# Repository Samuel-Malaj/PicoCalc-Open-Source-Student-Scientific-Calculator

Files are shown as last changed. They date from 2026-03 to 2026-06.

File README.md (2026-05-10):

# PicoCalc-Open-Source-Student-Scientific-Calculator
Open source scientific calculator built on Raspberry Pi Pico W — custom PCB, WiFi messaging, IR projector control and games.

# PicoCalc — Open Source Student Scientific Calculator

A fully custom scientific calculator built on the Raspberry Pi Pico W, designed specifically for students. Features wireless peer-to-peer messaging, IR classroom projector control, a custom PCB, and built-in games — all running on MicroPython.

---

## Overview

PicoCalc is an end-to-end hardware and software project encompassing PCB design, embedded systems programming, wireless networking, and circuit design. Every component — from the button matrix to the IR driver circuit — was designed, calculated, and implemented from scratch.

This project was built entirely by a Year 10/11 student as an independent engineering project.

---

## Features

### Scientific Calculator
- Full arithmetic operations with correct operator precedence
- Scientific functions: sin, cos, tan, log, ln, sqrt, powers, factorials
- Degree and radian mode switching
- Expression history and ANS recall
- Error handling for invalid inputs and edge cases
- Custom expression parser built from scratch in MicroPython

### Peer-to-Peer Messaging
- Send and receive text messages between two PicoCalc devices over WiFi
- UDP broadcast protocol for low-latency local communication
- Designed for classroom use — share working, answers, or notes with a friend

### IR Projector Control
- 940nm IR LED with BC547 transistor driver circuit
- Compatible with Hitachi, Maxell, Epson and Samsung projectors and displays
- Up to 10 metre range achieved through transistor amplification
- Allows students to control classroom projectors from their desk
- NEC and SIRC IR protocol support

### Games
- Built-in simple games for use during breaks
- Runs entirely on the calculator hardware — no additional software needed

---

## Hardware

### Custom PCB
- Designed from scratch in KiCad
- Manufactured by PCBWay
- 2-layer PCB with row traces on F.Cu and column traces on B.Cu
- Dimensions: 75.5mm × 146mm

### Components
| Component | Description |
|---|---|
| Raspberry Pi Pico W | Main microcontroller with WiFi and Bluetooth |
| 38× 6mm Tactile Switches | Button matrix (THT, through hole) |
| TSAL6200 | 940nm IR LED, 3mm horizontal |
| BC547 | NPN transistor for IR LED driver |
| 22Ω Resistor | IR LED current limiting |
| 1kΩ Resistor | Transistor base protection |
| 2.42" SSD1309 OLED | 128×64 I2C display |
| 2× AA Battery Holder | MPD BC2AAPC, powers via VSYS |

### Button Matrix
- 38 buttons arranged in a row/column matrix
- GP0–GP7: row outputs
- GP8–GP15: column inputs with internal pull-up resistors
- Only 16 GPIO pins required for 38 buttons
- Scanning rate fast enough to never miss a keypress

### IR LED Circuit
- VSYS (3V from 2× AA) powers the LED circuit
- 22Ω current limiting resistor → 82mA through LED
- BC547 transistor switches the high current safely
- GPIO only supplies <2.6mA to the base — well within Pico's 16mA limit

### Power
- 2× AA batteries connected to VSYS pin
- Auto power-off via MicroPython lightsleep after inactivity
- Lightsleep current draw: ~1-2mA — significantly extends battery life

---

## Software

### MicroPython
- Written entirely in MicroPython
- Modular codebase — calculator, display, networking, IR all separate modules
- Custom expression parser for evaluating scientific expressions
- Uses built-in `math` library for scientific functions

### WiFi Communication
- Both devices connect to the same network
- UDP sockets for low-latency message transmission
- Graceful handling of connection drops and reconnection

---

## PCB Design

Designed in KiCad. Key design decisions:

- **2-layer routing**: Row traces on F.Cu, column traces on B.Cu — allows the button matrix grid to work without short circuits
- **Through hole components**: All buttons and connectors are THT for mechanical strength under repeated use
- **RF keepout zone**: Respected around the Pico W antenna to preserve WiFi/BLE signal strength
- **Removable Pico**: THT header holes allow the Pico W to be plugged in and removed — not permanently soldered
- **Battery on reverse**: Battery holder mounted on B.Cu to keep the front face clean

---

## Schematic & Design Files

- KiCad schematic and PCB layout files included in `/hardware`
- Gerber files included in `/hardware/gerbers`
- BOM included in `/hardware/BOM.csv`

---

## What I Learned

- PCB design and manufacturing process (KiCad → Gerber → PCBWay)
- Ohm's law applied to real circuit design (resistor calculations for IR LED and transistor)
- Button matrix design — why a matrix uses N+M pins instead of N×M
- Two-layer PCB routing and via usage
- MicroPython embedded programming on real hardware
- WiFi networking with UDP sockets on microcontrollers
- IR remote control protocols (NEC, SIRC)
- Debugging real hardware and firmware issues

---

## Project Status

- [x] PCB designed and ordered
- [x] Schematic complete
- [ ] IR LED circuit designed and verified
- [x] MicroPython calculator engine
- [ ] Display driver integration
- [x] WiFi messaging
- [ ] IR control implementation
- [ ] Games

---

## License

MIT License — free to use, modify and build upon.

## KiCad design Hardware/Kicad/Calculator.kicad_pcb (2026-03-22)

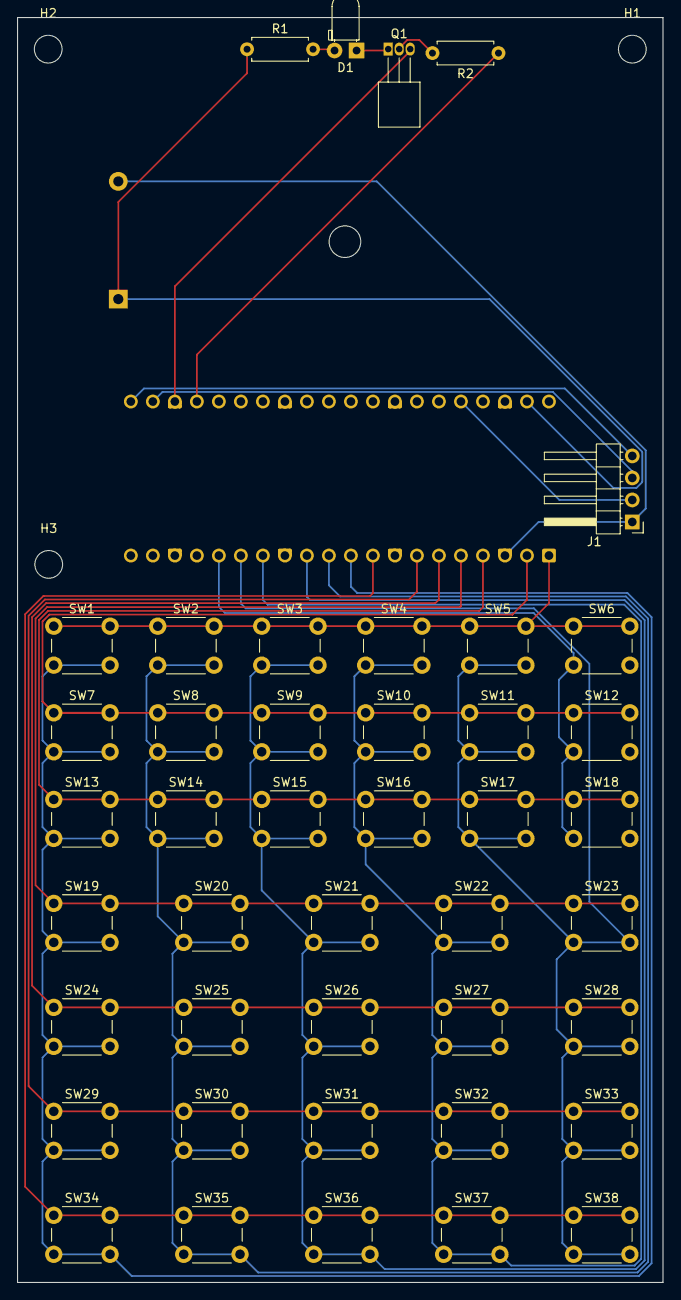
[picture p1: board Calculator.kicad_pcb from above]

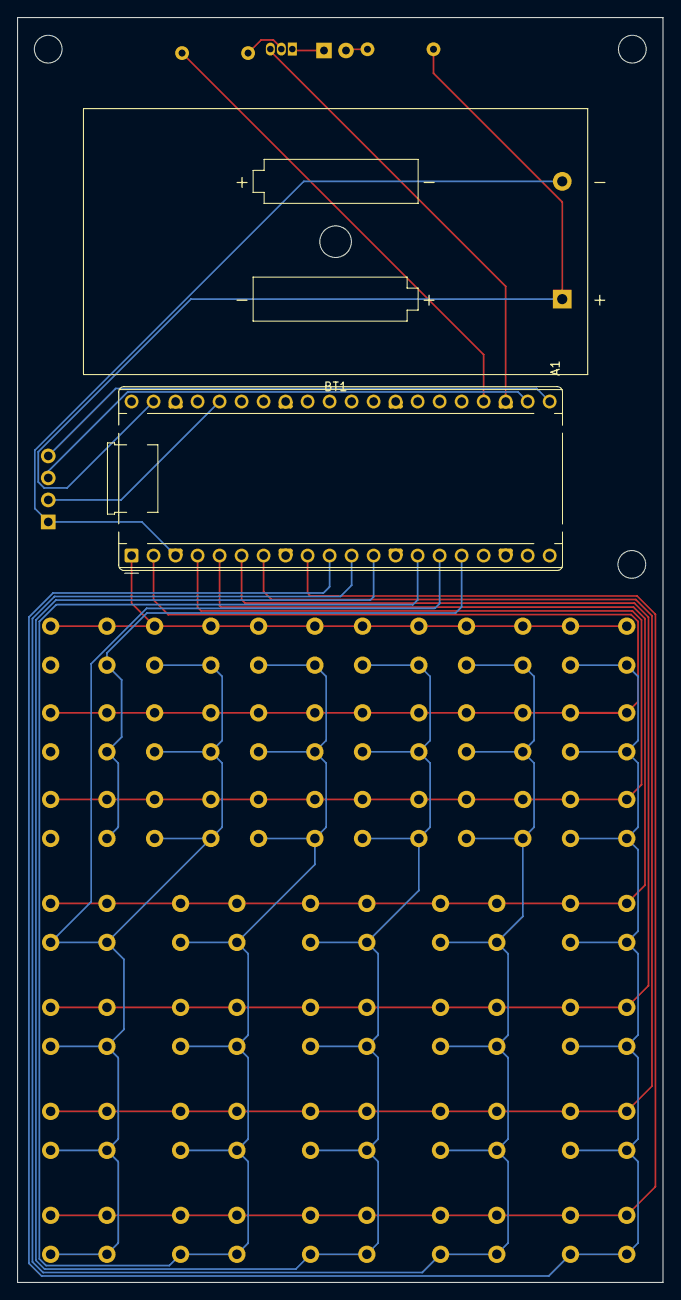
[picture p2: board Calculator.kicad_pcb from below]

Board: 2 copper layers, 74.5 x 146.0 mm, 48 parts (2 on the bottom side), 22 nets.

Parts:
A1: RaspberryPi_Pico_W; RaspberryPi_Pico_Common_THT
BT1: Battery; BatteryHolder_MPD_BC2AAPC_2xAA
D1: TSAL6200; LED_D3.0mm_Horizontal_O1.27mm_Z2.0mm_IRGrey
H1, H2, H3: MountingHole; MountingHole_3.2mm_M3
J1: Conn_01x04; PinHeader_1x04_P2.54mm_Horizontal
Q1: BC547; TO-92_Inline_Horizontal1
R1: 22R; R_Axial_DIN0207_L6.3mm_D2.5mm_P7.62mm_Horizontal
R2: 1000R; R_Axial_DIN0207_L6.3mm_D2.5mm_P7.62mm_Horizontal
SW1, SW2, SW3, SW4, SW5, SW6, SW7, SW8, SW9, SW10, SW11, SW12, SW13, SW14, SW15, SW16, SW17, SW18, SW19, SW20, SW21, SW22, SW23, SW24, SW25, SW26, SW27, SW28, SW29, SW30, SW31, SW32, SW33, SW34, SW35, SW36, SW37, SW38: SW_Push_Dual_x2; SW_PUSH_6mm_H4.3mm

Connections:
unnamed: A1.36 (3V3), J1.2
unnamed: A1.1 (GPIO0), SW1.1 (C), SW2.1 (C), SW3.1 (C), SW4.1 (C), SW5.1 (C), SW6.1 (C)
unnamed: A1.2 (GPIO1), SW7.1 (C), SW8.1 (C), SW9.1 (C), SW10.1 (C), SW11.1 (C), SW12.1 (C)
unnamed: A1.4 (GPIO2), SW13.1 (C), SW14.1 (C), SW15.1 (C), SW16.1 (C), SW17.1 (C), SW18.1 (C)
unnamed: A1.5 (GPIO3), SW19.1 (C), SW20.1 (C), SW21.1 (C), SW22.1 (C), SW23.1 (C)
unnamed: A1.6 (GPIO4), SW24.1 (C), SW25.1 (C), SW26.1 (C), SW27.1 (C), SW28.1 (C)
unnamed: A1.7 (GPIO5), SW29.1 (C), SW30.1 (C), SW31.1 (C), SW32.1 (C), SW33.1 (C)
unnamed: A1.9 (GPIO6), SW34.1 (C), SW35.1 (C), SW36.1 (C), SW37.1 (C), SW38.1 (C)
unnamed: A1.10 (GPIO7), SW1.2 (D), SW7.2 (D), SW13.2 (D), SW19.2 (D), SW24.2 (D), SW29.2 (D), SW34.2 (D)
unnamed: A1.11 (GPIO8), SW2.2 (D), SW8.2 (D), SW14.2 (D), SW20.2 (D), SW25.2 (D), SW30.2 (D), SW35.2 (D)
unnamed: A1.12 (GPIO9), SW3.2 (D), SW9.2 (D), SW15.2 (D), SW21.2 (D), SW26.2 (D), SW31.2 (D), SW36.2 (D)
unnamed: A1.14 (GPIO10), SW4.2 (D), SW10.2 (D), SW16.2 (D), SW22.2 (D), SW27.2 (D), SW32.2 (D), SW37.2 (D)
unnamed: A1.15 (GPIO11), SW5.2 (D), SW11.2 (D), SW17.2 (D), SW23.2 (D), SW28.2 (D), SW33.2 (D), SW38.2 (D)
unnamed: A1.16 (GPIO12), SW6.2 (D), SW12.2 (D), SW18.2 (D)
unnamed: A1.21 (GPIO16), J1.4
unnamed: A1.22 (GPIO17), J1.3
unnamed: A1.24 (GPIO18), R2.1
unnamed: A1.39 (VSYS), BT1.1 (+), R1.1
unnamed: A1.3 (GND), A1.8 (GND), A1.13 (GND), A1.18 (GND), A1.23 (GND), A1.28 (GND), A1.38 (GND), BT1.2 (-), J1.1, Q1.3 (E)
unnamed: D1.2 (A), R1.2
unnamed: D1.1 (K), Q1.1 (C)
unnamed: Q1.2 (B), R2.2

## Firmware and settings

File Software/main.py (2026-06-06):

import gc
from machine import Pin
import utime as time
import network
import errno
from icons import *
from inputs import *
from WiFi import *
from modes import *
from utils import *

LED = Pin('LED', Pin.OUT)
while True:
    try:
        from OLED import *
        break
    except Exception as e:
        print(e)
        LED.toggle()
        time.sleep(0.5)
        LED.toggle()

##############################################################################
#print('Switching off')
#power_off()

''' Main '''
def main():
    while True:
        print('RAM:',gc.mem_free())
        mode = main_menu()
        indicate_wifi()
        clear_mode_line()
        clear_main()
        print('RAM:',gc.mem_free())
        
        if mode == 'calc mode':
            append_output('Calc Mode', 0, 0)
            calculator(expression)

        if mode == 'notepad mode':
            append_output('Notepad', 0, 0)
            note_pad(expression)
            
        if mode == 'WiFi':
            wifi()
            
        if mode == 'sms mode':
            append_output('SMS Mode', 0, 0)
            if ap.active() or wlan.isconnected():
                asyncio.run(messaging())
            else:
                append_output('Unavailable', 0, 10)
                append_output('No Wi-Fi', 0, 20)
                time.sleep(1.5)
                
        if mode == 'whatsapp':
            append_output('Whatsapp', 0, 0)
            if wlan.isconnected():
                send_whatsapp()
            else:
                append_output('Unavailable', 0, 10)
                append_output('No WiFi', 0, 20)
                time.sleep(1.5)
                
        if mode == 'games':
            game_select()
            
        if mode == 'weather':
            print('RAM:',gc.mem_free())
            weather()
                
main()

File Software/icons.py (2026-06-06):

from machine import I2C, Pin
from ssd1309 import SSD1309
import framebuf

oled = SSD1309(sda=16, scl=17, addr=0x3D)

start_up_icon = [
    0b00000000000000000000000000000000000000000000000000000000000000000000000000000000000000000000000000000000000000000000000000000000,
    0b00000000000000000000000000000000000000000000000000000000000000000000000000000000000000000000000000000000000000000000000000000000,
    0b00000000000000000000000000000000000000000000000000000000000000000000000000000000000000000000000000000000000000000000000000000000,
    0b00000000000000000000000000000000000000000000000000000000000000000000000000000000000000000000000000000000000000000000000000000000,
    0b00000000000000000000000000000000000000000000000000000000000100000000000000000000000000000000000000000000000000000000000000000000,
    0b00000000000000000000000000000000000000000000000000000000000100000000000000000000000000000000000000000000000000000000000000000000,
    0b00000000000000000000000000000000000000000000000000000000000100000000010000000000000000000000000000000000000000000000000000000000,
    0b00000000000000000000000000000000000000000000000000000000000100000000010000000000000000000000000000000000000000000000000000000000,
    0b00000000000000000000000000000000000000000000000000000000000100000000010000000000000000000000000000000000000000000000000000000000,
    0b00000000000000000000000000000000000000000000000000000000000100000000010000000000000000000000000000000000000000000000000000000000,
    0b00000000000000000000000000000000000000000000000000000000000100000000110000000000000000000000000000000000000000000000000000000000,
    0b00000000000000000000000000000000000000000000000000000000000100000000100000000000000000000000000000000000000000000000000000000000,
    0b00000000000000000000000000000000000000000000000000000000000100000000100000000000000000000000000000000000000000000000000000000000,
    0b00000000000000000000000000000000000000000000000000000000000100000000100000000000000000000000000000000000000000000000000000000000,
    0b00000000000000000000000000000000000000000000000000000000000100000000100000000000000000000000000000000000000000000000000000000000,
    0b00000000000000000000000000000000000000000000000000000000000000000000100000000000000000000000000000000000000000000000000000000000,
    0b00000000000000000000000000000000000000000000000000000000000000000000100000000000000000000000000000000000000000000000000000000000,
    0b00000000000000000000000000000000000000000000000000000000000000000000100000000000000000000000000000000000000000000000000000000000,
    0b00000000000000000000000000000000000000000000000000000000000000000000000000000000000000000000000000000000000000000000000000000000,
    0b00000000000000000000000000000000000000000000000000000000000000000000000000000000000000000000000000000000000000000000000000000000,
    0b00000000000000000000000000000000000000000000000000000000000000000000000000000000000000000000000000000000000000000000000000000000,
    0b00000000000000000000000000000000000000000000000001000000000000000000000000000110000000000000000000000000000000000000000000000000,
    0b00000000000000000000000000000000000000000000000001000000000000000000000000000100000000000000000000000000000000000000000000000000,
    0b00000000000000000000000000000000000000000000000001000000000000000000000000000010000000000000000000000000000000000000000000000000,
    0b00000000000000000000000000000000000000000000000011000000000000000000000000000010000000000000000000000000000000000000000000000000,
    0b00000000000000000000000000000000000000000000000110000000000000000000000000000010000000000000000000000000000000000000000000000000,
    0b00000000000000000000000000000000000000000000001100000000000000000000000000000001000000000000000000000000000000000000000000000000,
    0b00000000000000000000000000000000000000000000111100000000000000000000000000000001000000000000000000000000000000000000000000000000,
    0b00000000000000000000000000000000000000111000111110000000000000000000000000000001000000000000000000000000000000000000000000000000,
    0b00000000000000000000000000000000000000001111100110000000000000000000000000000001110000000000000000000000000000000000000000000000,
    0b00000000000000000000000000000000000000000000000011100000000000000000000000000011111100000000000000000000000000000000000000000000,
    0b00000000000000000000000000000000000000000000000000111000000000000000000000000010000000000000000000000000000000000000000000000000,
    0b00000000000000000000000000000000000000000000000000001110000000000000000000001110000000000000000000000000000000000000000000000000,
    0b00000000000000000000000000000000000000000000000000000011110000000000000000111000000000000000000000000000000000000000000000000000,
    0b00000000000000000000000000000000000000000000000000000000011110000000001111000000000000000000000000000000000000000000000000000000,
    0b00000000000000000000000000000000000000000000000000000000000011111111111000000000000000000000000000000000000000000000000000000000,
    0b00000000000000000000000000000000000000000000000000000000000000000000000000000000000000000000000000000000000000000000000000000000,
    0b00000000000000000000000000000000000000000000000000000000000000000000000000000000000000000000000000000000000000000000000000000000,
    0b00000000000000000000000000000000000000000000000000000000000000000000000000000000000000000000000000000000000000000000000000000000,
    0b00000000000000000000000011111000000000000000000000000000000000000000000000000000000000000000000000000000000000000000000000000000,
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
]
########## small icons ##########
WIFI = [
    0b0111111110,
    0b1000000001,
    0b0011111100,
    0b0100000010,
    0b0001111000,
    0b0010000100,
    0b0000110000, 
    0b0000110000,
    0b0000000000,
    0b0000000000, 
]

SHIFT = [
    0b1011111101,
    0b1011000001,
    0b1011000001,
    0b1011111101,
    0b1000001101,
    0b1000001101,
    0b1011111101,
]

NO_WIFI = [
    0b0111111110,
    0b1011001101,
    0b0011111100,
    0b0100110010,
    0b0001111000,
    0b0011001100,
    0b0110110110,
    0b0000110000, 
    0b0000000000,
    0b0000000000,
]

ALPHA = [
    0b1000110001, 
    0b1001111001,
    0b1011001101, 
    0b1011001101, 
    0b1011111101,
    0b1010000101,
    0b1010000101,
    0b1000000001,
]

NUMERICAL = [
    0b1000110001,
    0b1011110001,
    0b1000110001,
    0b1000110001,
    0b1000110001, 
    0b1000110001, 
    0b1011111101, 
    0b1011111101,  
]
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

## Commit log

2026-03-28 Add button press detection in main.py
    Implement button press detection using GPIO pins.
2026-03-29 Updated to incorporate calculations controlled by button presses
    Program now uses imputed button presses to calculate expression and output an answer
2026-03-29 Refactor scientific calculations and error handling
    Enhance scientific operator handling and improve error management.
    [Calculate.py]
2026-03-31 Enhance error handling in calculation methods and handles brackets
    Added error handling for various exceptions in calculation functions and improved the handling of mathematical errors.
    [Calculate.py]
2026-04-29 Refactor calculator input handling and button logic
2026-05-08 Implement asyncio and socket for Wi-Fi text message communication
    Refactor calculator and character handling with asyncio for better concurrency and responsiveness and to allow simultaneous sending and receiving of text messages over Wi-Fi.
2026-05-10 new file for power management
    File allows Pico to switch of upon power button press
2026-05-10 Implement messaging and Power Off function
    Added use of socket and asyncio to simultaneously send and receive broadcasted UDP messages over Wi-Fi and implemented lowpower.py to allow pico to go into sleep mode upon press of power button.
2026-05-22 Updated to control OLED module and display inputs/outpus
    Incorporates OLED.py file defining simple functions to control OLED module, using SSD1309 driver, and display inputs and outputs
2026-05-23 Refactor main.py for enhanced functionality and display
    Updated calculator and character arrays to include new functions and improved display handling. Enhanced error handling and added WiFi connection features including WiFi icons and shift icon.
    [main.py]
2026-05-26 Added more python files for organisation
    Files pack most main.py functions into 3 separate files for tidier code. Functions including WiFi connectivity, mode functions, input functions and socket preparation.
2026-05-27 New icons added
    new icons such as 'No WiFi' icon and numerical indicator and alpha indicator to indicate to the user if the current input mode is numerical or alphabetical.
2026-05-27 Refactor main function for better clarity and flow
2026-05-28 fix: remove sensitive info
    [modes.py]
2026-05-28 Refactor main.py and update Wi-Fi handling
    Refactor main.py to improve functionality and readability. Updated Wi-Fi connection checks and removed unused power_off function.
2026-05-28 refactor: move power off function to utils.py
2026-05-28 fix: patch bug in messaging()
    Bug prevented Pico from receiving UDP messages. Pico can now simultaneously send and receive messages.
    [modes.py]
2026-05-28 fix: patch bug in messaging()
    FIxed bug which prevented messaging() from being run multiple times as a result of the definition of variable stop_event. Bug now fixed.
    [modes.py]
2026-05-29 feat: use framebuffer blit for faster icon rendering
2026-05-30 Fix: patch bug in Tic Tac Toe + Feat: add tie recognition
    [modes.py]
2026-06-04 Refactor main_menu and button selection logic
    Refactor main_menu to use a list for modes and update button handling.
2026-06-04 Fix: patch bug in Tic Tac Toe
    [modes.py]
